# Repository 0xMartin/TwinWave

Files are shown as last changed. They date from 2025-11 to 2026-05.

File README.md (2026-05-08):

<div align="center">

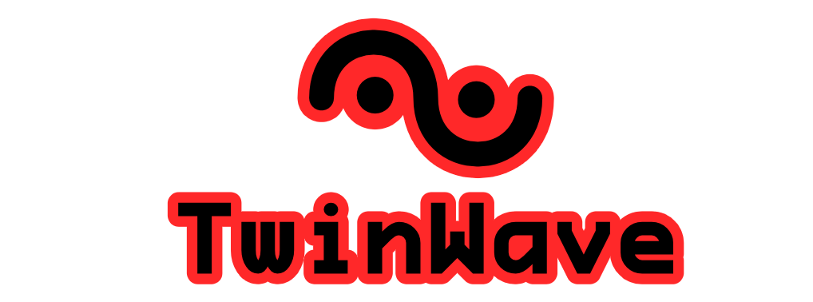
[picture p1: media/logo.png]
TwinWave Logo


#### Wi‑Fi & Sub‑GHz GPIO Module for Flipper Zero

🌐 **[View Project Website](https://0xmartin.github.io/TwinWave/)** 🌐

📋 **[View PCB Project on OSHWLab](https://oshwlab.com/martin.krcma1/flipper-wifi-and-433mhz-shield)** 📋






Compact GPIO module designed for Flipper Zero, combining 2.4 GHz Wi-Fi and 433 MHz Sub-GHz.

</div>

<div align="center">

<table>
<tr>
<td align="center" width="50%">
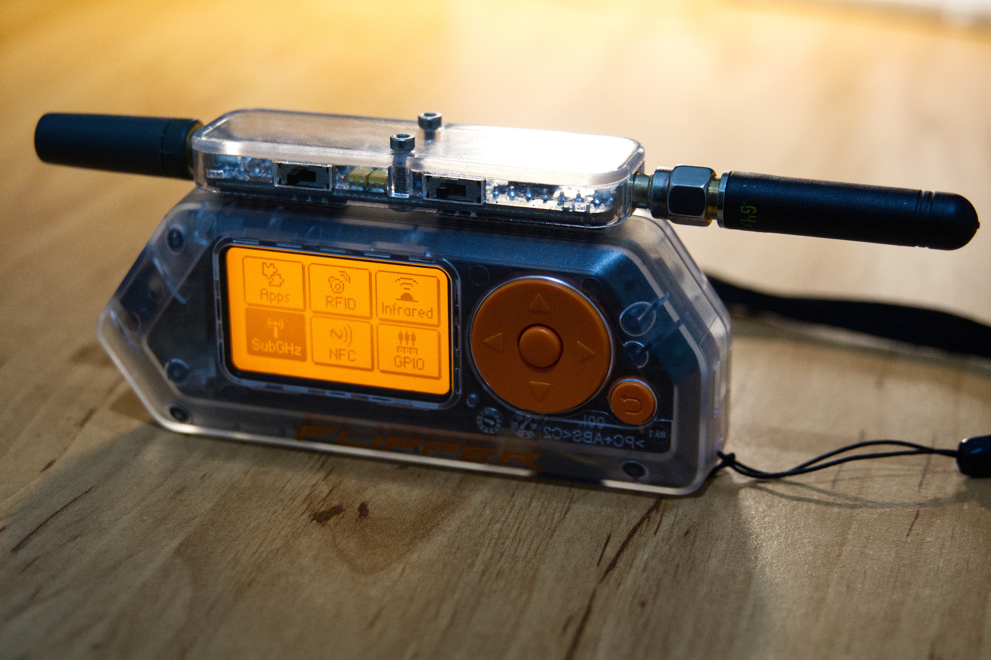
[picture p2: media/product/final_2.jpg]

</td>
<td align="center" width="50%">
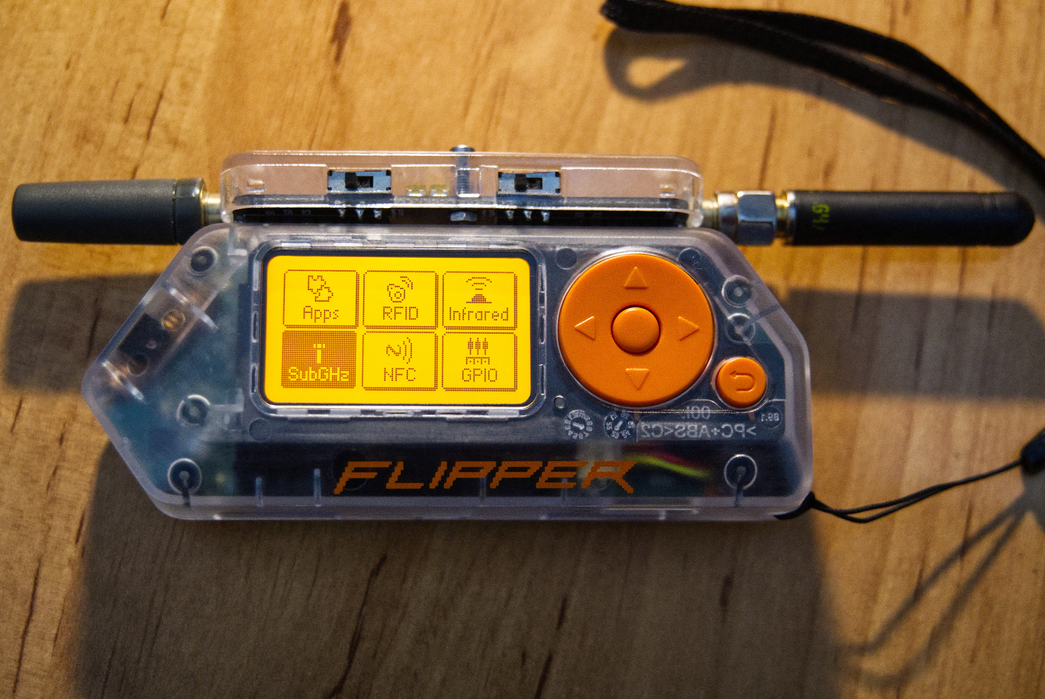
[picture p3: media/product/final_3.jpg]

</td>
</tr>
</table>

<br>

<a href="https://youtu.be/bnLjusv_fXI">
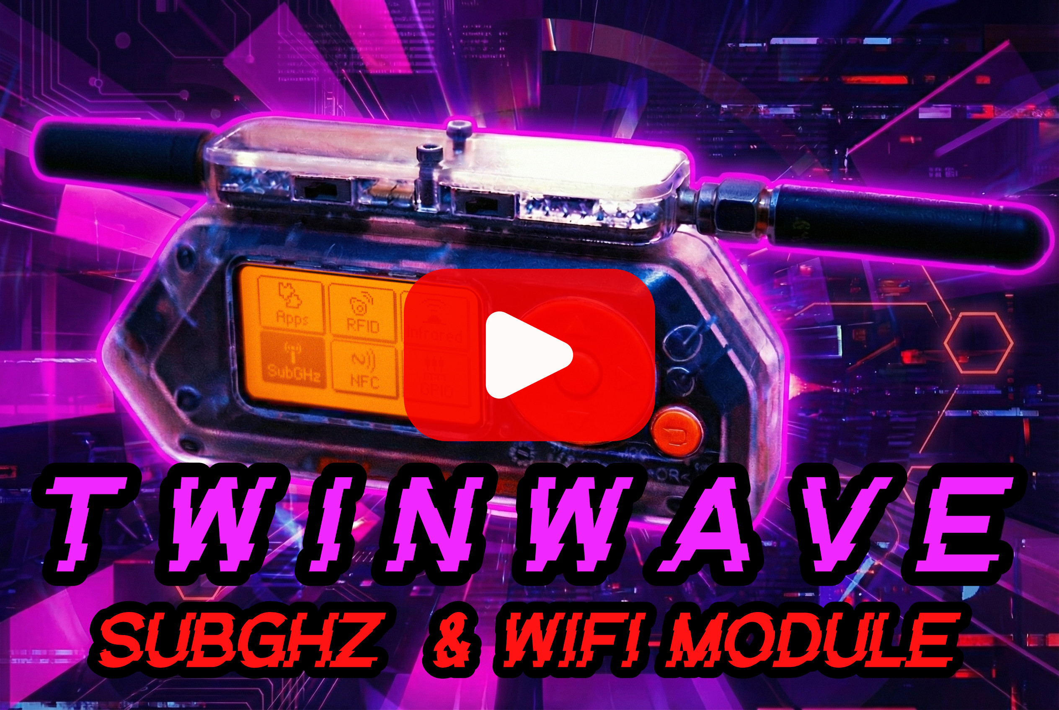
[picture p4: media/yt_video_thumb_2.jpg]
Watch the video
    
</a>

<br>

<sub><em>📺 Click to watch TwinWave in action on YouTube</em></sub>

</div>

<br>

The module is designed to be **as compact as possible**, with replaceable antennas and the ability to remain permanently installed in the port. Two micro switches allow you to activate or deactivate the Wi‑Fi and Sub‑GHz radios, preventing unnecessary power draw when not in use.

<br>

### 📦 Manufacturing Files & Project

- **PCB Manufacturing:** Gerber files, Bill of Materials (BOM), and Pick and Place data for PCB manufacturing are available in the **[./hardware/export](./hardware/export)** directory.
- **EasyEDA Project:** The complete PCB project can be found in the **[./hardware](./hardware)** directory and can be opened in **EasyEDA Pro**.
- **PCB Stackup:** Use **JLC04161H-7628** (4-layer, 1.6mm, 7628 prepreg). This is a standard JLCPCB stackup with the following layer structure:
  | Layer | Material | Thickness |
  |-------|----------|----------|
  | Top Layer | Copper | 0.035mm |
  | Prepreg | 7628×1 | 0.21040mm |
  | Inner Layer L2 | Copper | 0.0152mm |
  | Core | Core | 1.065mm |
  | Inner Layer L3 | Copper | 0.0152mm |
  | Prepreg | 7628×1 | 0.21040mm |
  | Bottom Layer | Copper | 0.035mm |
  
  Total thickness: ~1.1mm H/HOZ with copper
 
> [!NOTE]
> **Pin Header Assembly:** It is recommended to **assemble the pin header yourself** (GPIO connector). This allows you to **adjust the pin length** to perfectly fit your specific Flipper Zero configuration – whether it has a protective case or not.

---

## ✨ Key Features

<table>
<tr>
<td width="50%">

### 🔌 Hardware
- **Dual radios** – Wi‑Fi 2.4 GHz + Sub‑GHz 433 MHz
- **Replaceable antennas** – 2× SMA female connectors
- **Power switches** – Independent Wi‑Fi/Sub‑GHz power control
- **Compact design** – Small form factor for easy use in any situation

</td>
<td width="50%">

### 💻 Software & Chips
- **ESP32-PICO-V3-02** – Wi‑Fi connectivity
- **TI CC1101** – Sub‑GHz transceiver
- **Marauder compatible** – ESP32 Marauder support
- **Easy updates** – UART firmware flashing

</td>
</tr>
</table>

---

## 📋 Technical Specifications

| Category | Details |
|---|---|
| **Radios** | Wi‑Fi 2.4 GHz (ESP32‑PICO‑V3‑02) <br> Sub‑GHz 433 MHz (TI CC1101) |
| **Antennas** | 2× SMA female connectors (Wi‑Fi + 433 MHz) |
| **Power** | Supplied from Flipper GPIO (3.3V, GND) |
| **ESP32 Interface** | UART/Serial via Flipper GPIO <br> Firmware update via external USB‑TTL |
| **CC1101 Interface** | SPI bus (shared with Flipper) |
| **Indicators** | Power LEDs and ESP32 RX and TX LEDs |
| **Compatibility** | Flipper Zero with GPIO header |
| **Dimensions** | Compact form factor, designed for permanent installation |

---

## ⚡ Power Consumption

<details>
<summary><b>📊 Click to view Power Consumption Measurements</b></summary>

<br>

Power consumption measured using oscilloscope in different operating modes:

<div align="center">

<table>
    <tr>
        <td align="center">
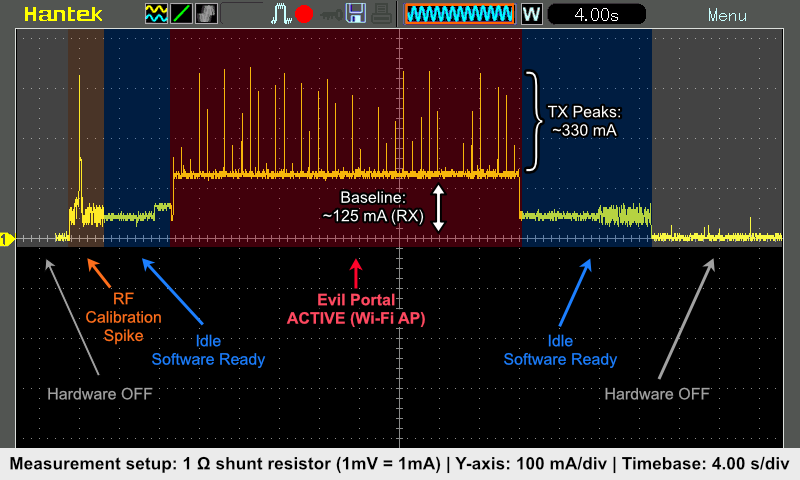
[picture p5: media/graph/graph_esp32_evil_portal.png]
Power consumption - Evil Portal mode
            <br/>
            <sub><strong>Evil Portal Mode</strong> – Power consumption during Evil Portal operation</sub>
        </td>
    </tr>
    <tr>
        <td align="center">
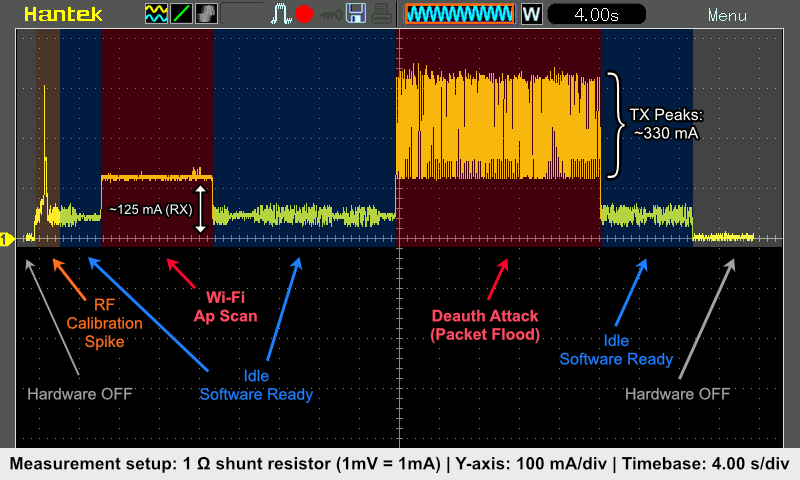
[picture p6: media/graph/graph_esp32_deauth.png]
Power consumption - ESP32 Deauth
            <br/>
            <sub><strong>ESP32 Deauth Detail</strong> – Detailed ESP32 power draw during deauthentication activity</sub>
        </td>
    </tr>
    <tr>
        <td align="center">
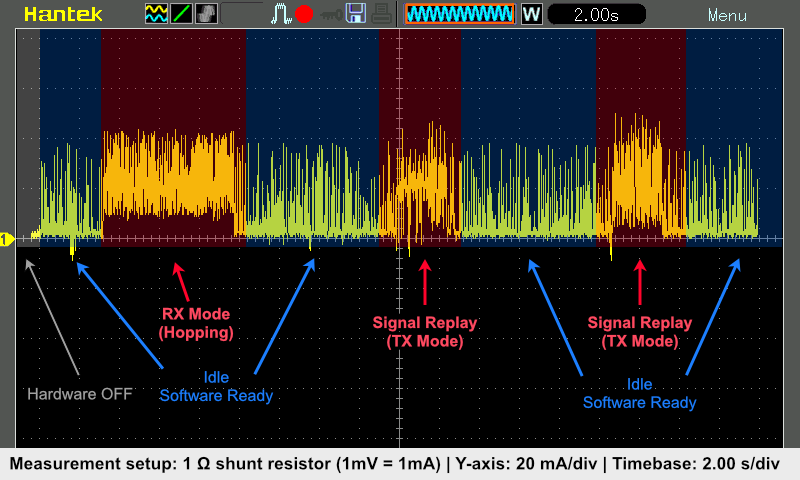
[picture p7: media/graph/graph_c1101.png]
Power consumption - CC1101 Detail
            <br/>
            <sub><strong>CC1101 Detail</strong> – Detailed CC1101 power draw during read/replay activity</sub>
        </td>
    </tr>
</table>

</div>

> [!NOTE]
> These measurements help you understand the power requirements when using the module with Flipper Zero. Use the power switches to disable unused radios and save battery.

</details>

---

## ⚙️ Quick Start Guide

### Step-by-Step

1. **📡 Attach Antennas**
   - Connect 2.4 GHz antenna to the Wi‑Fi SMA connector
   - Connect 433 MHz antenna to the Sub‑GHz SMA connector

2. **🔌 Install Module**
   - Carefully plug the module onto Flipper Zero's GPIO header
   - Ensure proper alignment and secure connection

3. **⚡ Enable Radios**
   - Use micro switches to enable Wi‑Fi and/or Sub‑GHz as needed
   - LEDs will indicate active radios

4. **🚀 Start Experimenting**
   - Use Flipper's serial/terminal to interact with ESP32
   - Integrate CC1101 into your Sub‑GHz workflows

> [!WARNING]
> **Never transmit without antennas connected!** This can damage the RF stages.

---

## 🛠️ ESP32 Marauder Firmware

> [!NOTE]
> The firmware is a **port** of [ESP32 Marauder](https://github.com/justcallmekoko/ESP32Marauder) by **justcallmekoko**, specifically adapted for the `ESP32-PICO-V3-02` chip.

### 📥 Downloads & Flashing

Download precompiled binaries from repository releases: **`MARAUDER-vX.Y.Z-ESP32-PICO-V3-02.zip`**

#### ⚡ Web Flasher (Recommended)

The easiest way to flash firmware — directly from your browser, no installation required!

**[🚀 Open Web Flasher](https://0xmartin.github.io/TwinWave/flash.html)**

- ✓ Automatically downloads the latest firmware version
- ✓ Supports custom firmware upload
- ✓ Works in Chrome, Edge, and Opera browsers
- ✓ Step-by-step wizard guides you through the process

📖 **For manual flashing instructions and build guide, see [`firmware/README.md`](./firmware/README.md)**

---

## 📐 Technical Documentation

<details>
<summary><b>🔍 Click to view Schematic</b></summary>

<br>

<div align="center">
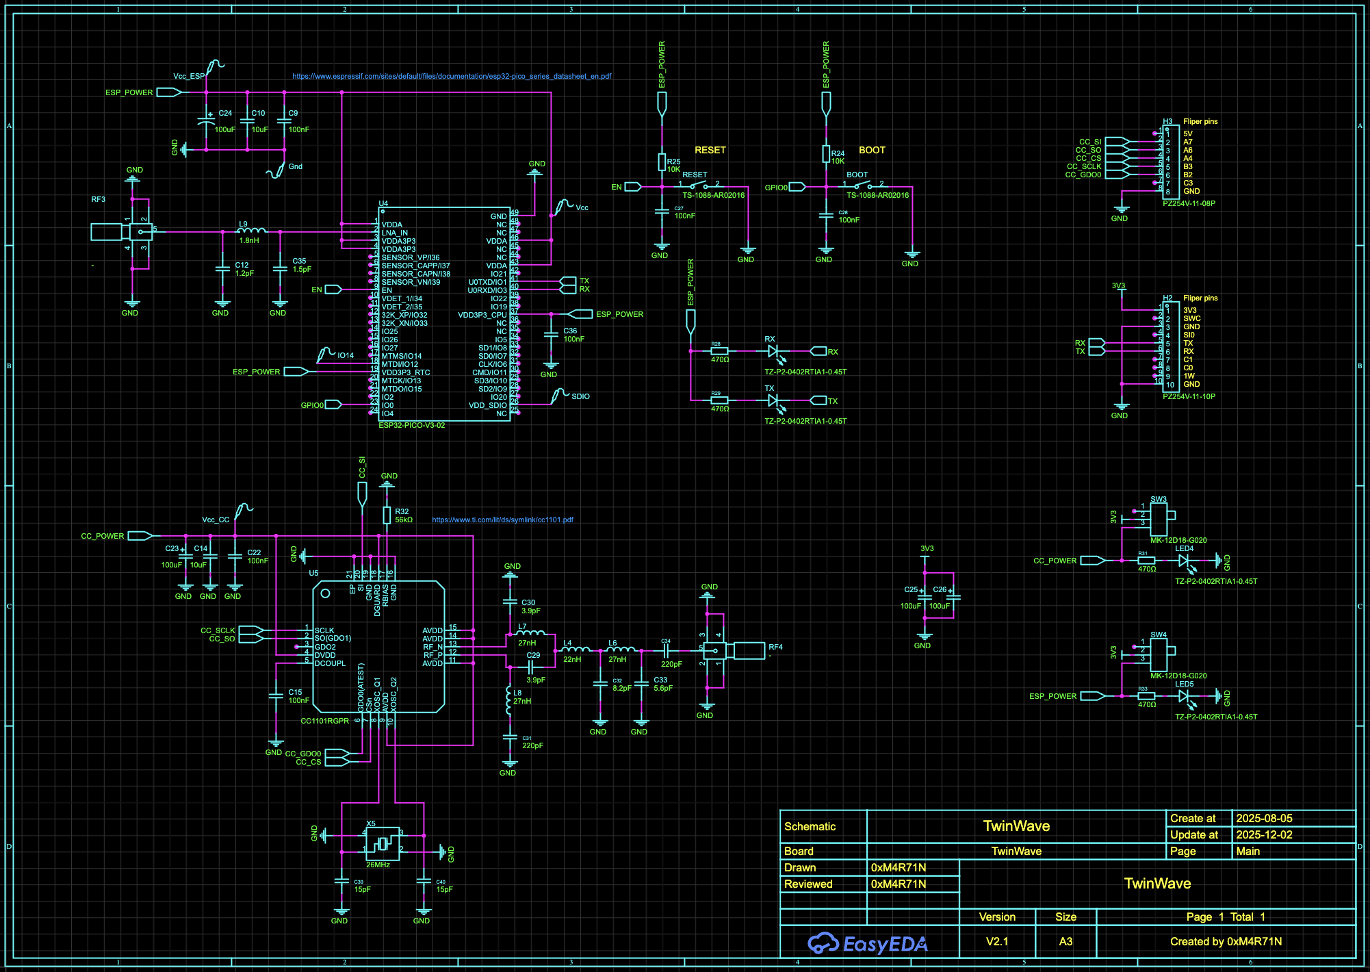
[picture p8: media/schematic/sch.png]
Circuit Schematic
    
    <sub><em>Complete circuit schematic with pinout details</em></sub>
</div>

</details>

<details>
<summary><b>🔍 Click to view PCB Design</b></summary>

<br>

<div align="center">
    <table>
        <tr>
            <td align="center" width="50%">
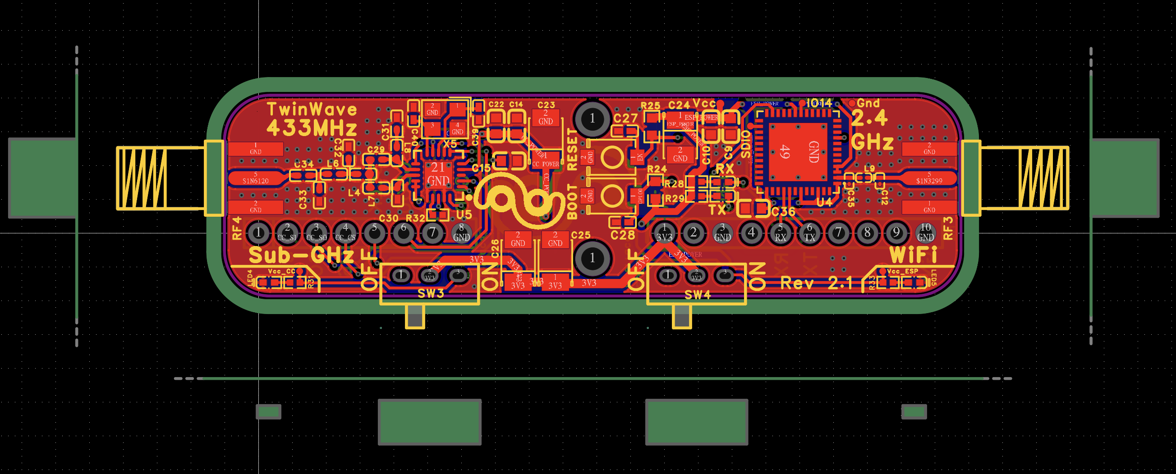
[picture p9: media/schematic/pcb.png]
PCB Top View
                <br/>
                <sub><strong>Top View</strong> – Component placement</sub>
            </td>
            <td align="center" width="50%">
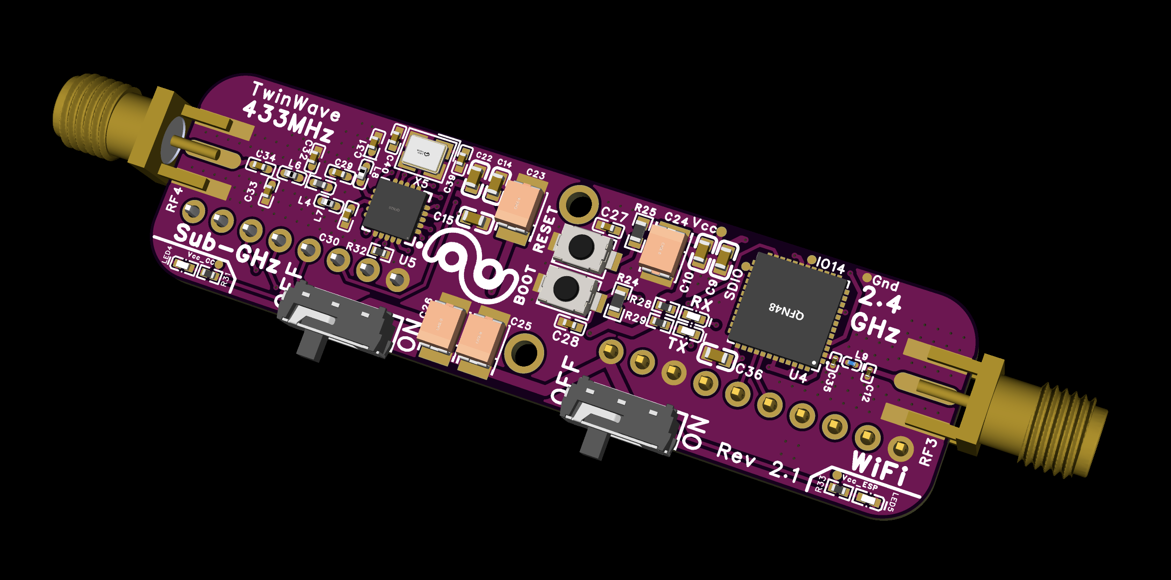
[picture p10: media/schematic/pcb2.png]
PCB 3D View
                <br/>
                <sub><strong>3D View</strong> – Layout visualization</sub>
            </td>
        </tr>
    </table>
</div>

</details>

<details>
<summary><b>📦 Click to view Case Dimensions</b></summary>

<br>

<div align="center">
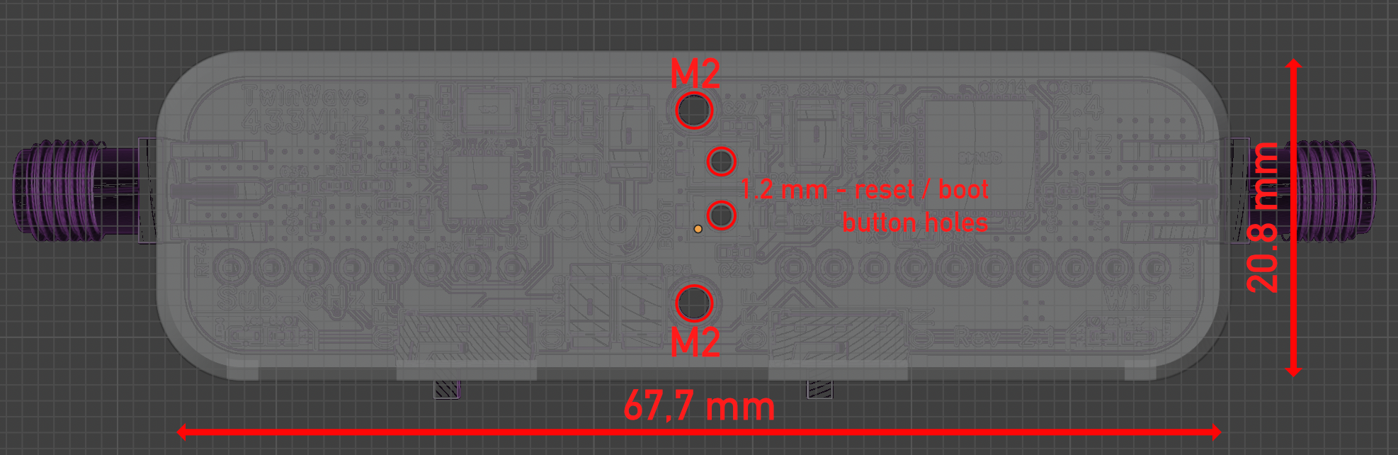
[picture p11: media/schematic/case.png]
Case Dimensions
    
    <sub><em>Case dimensions and form factor</em></sub>
</div>

</details>

---

## ⚠️ RF Safety & Legal

> [!WARNING]
> - **NEVER transmit without antenna connected** – can damage RF stages
> - Use properly tuned antennas for 2.4 GHz and 433 MHz
> - User is **fully responsible** for legal compliance
> - **Lab/experimental use only** – not certified for commercial use
> - Do NOT use in life‑support or safety‑critical systems

---

## 📜 License & Credits

### License

**Hardware:** [CC-BY-NC-SA-4.0 (Creative Commons Attribution-NonCommercial-ShareAlike)](hardware/LICENSE.txt)

**Firmware:** [MIT License (Based on ESP32 Marauder)](firmware/LICENSE.txt)

For details, see the LICENSE file in each subfolder.

**NOTICE:** The firmware is a derivative work of ESP32 Marauder by justcallmekoko, used under the MIT License. See [firmware/NOTICE](firmware/NOTICE).

### 👨‍💻 Authors
<table>
<tr>
<td>

**🔧 Hardware Design**  
[0xM4R71N](https://github.com/0xMartin) – PCB design, 3D case, Marauder port for ESP32-PICO-V3-02

</td>
</tr>
<tr>
<td>

**💻 Original Firmware**  
[justcallmekoko](https://github.com/justcallmekoko) – ESP32 Marauder firmware author

</td>
</tr>
</table>

---

<div align="center">

### 🌟 If you find this project useful, please consider giving it a star!



__Made with ❤️ for the Flipper Zero communit__

</div>

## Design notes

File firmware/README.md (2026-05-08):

# ESP32 Marauder Firmware

> ⚡ **Based on [ESP32 Marauder](https://github.com/justcallmekoko/ESP32Marauder) by [justcallmekoko](https://github.com/justcallmekoko)**
>
> This is a custom port adapted for the **TwinWave** module with `ESP32-PICO-V3-02` chip.
> All credit for the original firmware goes to the Marauder project and its contributors.

📖 For complete project documentation, see the [main README](../README.md)

---

## 📋 Overview

| Property | Value |
|---|---|
| **Base Firmware** | ESP32 Marauder v1.12.1 |
| **Target Chip** | ESP32-PICO-V3-02 |
| **Flash Size** | 8MB |
| **Framework** | Arduino (PlatformIO) |
| **Board Config** | `GENERIC_ESP32` |

---

## ⚡ Quick Start

### Option 1: Flash Precompiled Binaries

Download the latest release: **`MARAUDER-vX.Y.Z-ESP32-PICO-V3-02.zip`**

The package contains:
- `bootloader.bin` – ESP32 bootloader
- `firmware.bin` – Main firmware image
- `partitions.bin` – Partition table

**Flash using esptool:**

```bash
# Install esptool
pip install esptool

# Flash firmware (adjust port as needed)
esptool --chip esp32 --port /dev/cu.usbserial-0001 --baud 115200 write-flash -z \
    0x1000 bootloader.bin \
    0x8000 partitions.bin \
    0x10000 firmware.bin
```

> **Port examples:** `/dev/cu.usbserial-*` (macOS), `/dev/ttyUSB0` (Linux), `COM3` (Windows)

### Option 2: Build from Source

1. **Install PlatformIO** – [VS Code extension](https://platformio.org/install/ide?install=vscode) or CLI
2. **Open this folder** in VS Code with PlatformIO
3. **Connect USB-TTL adapter** to the TwinWave GPIO pins (see pinout below)
4. **Enter flash mode** – Hold BOOT, press RESET, release both
5. **Click Upload** (→) in PlatformIO toolbar

---

## 🔌 UART Connection (Flashing)

Connect a USB-TTL adapter (CP2102, CH340, FT232) to the **10-pin header** on the bottom of TwinWave PCB:

| TwinWave Pin | USB-TTL Adapter |
|---|---|
| Pin 1 (3V3) | VCC ⚠️ **3.3V only!** |
| Pin 3 (GND) | GND |
| Pin 5 (RX) | TX |
| Pin 6 (TX) | RX |

> ⚠️ **Warning:** Using 5V will permanently damage the ESP32!

### Enter Flash Mode

1. Hold **BOOT** button
2. Press **RESET** button
3. Release both buttons
4. The module is now in flash mode

---

### PlatformIO Settings

Key settings from [platformio.ini](platformio.ini):

```ini
platform = espressif32@5.2.0
board = esp32dev
framework = arduino
board_build.flash_mode = dio
board_build.partitions = default_8MB.csv
board_upload.flash_size = 8MB
```

### Dependencies

| Library | Version | Purpose |
|---|---|---|
| NimBLE-Arduino | ^1.4.1 | Bluetooth Low Energy |
| LinkedList | 0.0.0-alpha | Data structures |
| ESP32Ping | ^1.7 | Network diagnostics |
| AsyncTCP | latest | Async TCP connections |
| ESPAsyncWebServer | latest | Web server for Evil Portal |
| ArduinoJson | ^6.19.4 | JSON parsing |
| Adafruit MAX1704X | ^1.0.3 | Battery monitoring |
| MicroNMEA | ^2.0.6 | GPS parsing |
| EspSoftwareSerial | ^8.2.0 | Software serial communication |

---

## ⚠️ Troubleshooting

### Upload fails / "Failed to connect"

- Ensure you're in **flash mode** (BOOT + RESET sequence)
- Check USB-TTL connections (TX↔RX crossed)
- Try lower baud rate: `upload_speed = 57600`
- Verify correct serial port in `platformio.ini`

### "No serial data available"

- Check baud rate is **115200**
- Verify TX/RX connections
- Try different USB-TTL adapter

### Build errors

- Run `pio pkg update` to update libraries
- Clean build: `pio run -t clean`
- Check PlatformIO version compatibility

---

## 📜 Credits & License

- **Original Firmware:** [justcallmekoko](https://github.com/justcallmekoko) – ESP32 Marauder
- **Port/Adaptation:** [0xM4R71N](https://github.com/0xMartin) – ESP32-PICO-V3-02 adaptation

> ⚖️ This firmware is subject to the original [ESP32 Marauder license](https://github.com/justcallmekoko/ESP32Marauder). See the original repository for license terms.

---

## 🔗 Links

- 🏠 [TwinWave Project](https://github.com/0xMartin/TwinWave)
- 🌐 [Project Website](https://0xmartin.github.io/TwinWave/)
- 📖 [ESP32 Marauder Wiki](https://github.com/justcallmekoko/ESP32Marauder/wiki)
- 🛠️ [PlatformIO Documentation](https://docs.platformio.org/)

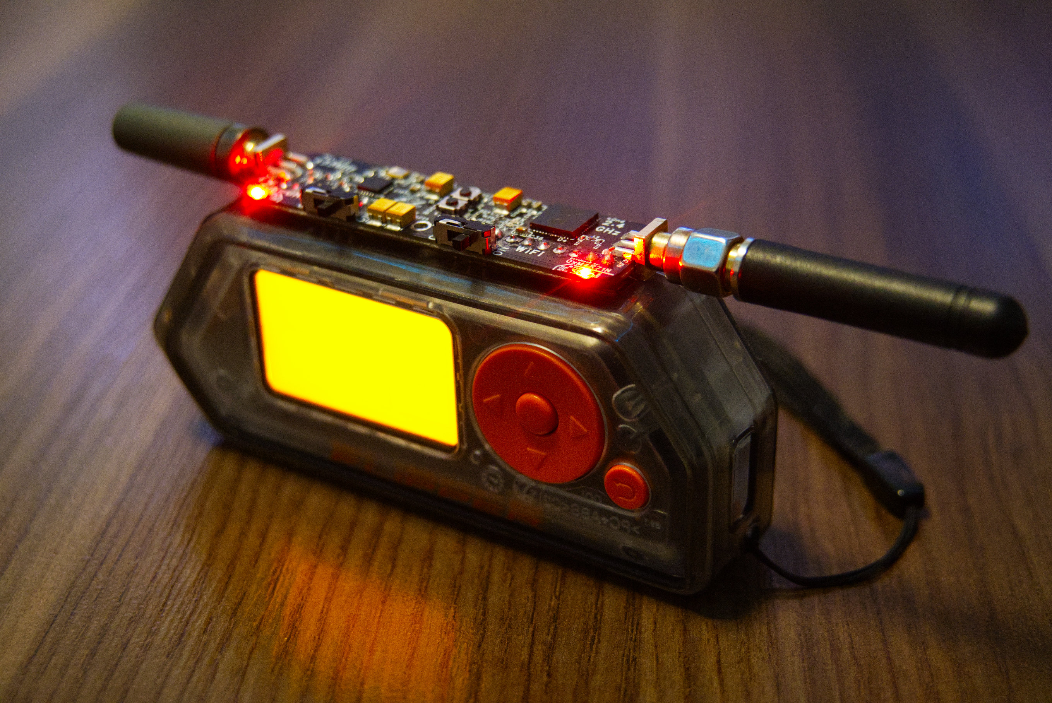
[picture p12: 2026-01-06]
media/product/final_6.jpg

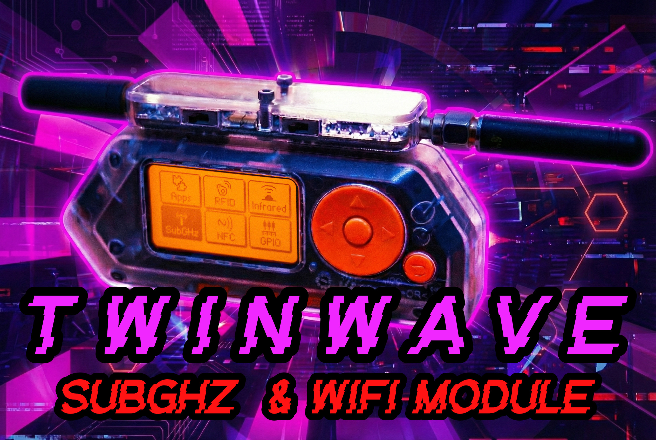
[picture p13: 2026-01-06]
media/yt_video_thumb_1.jpg

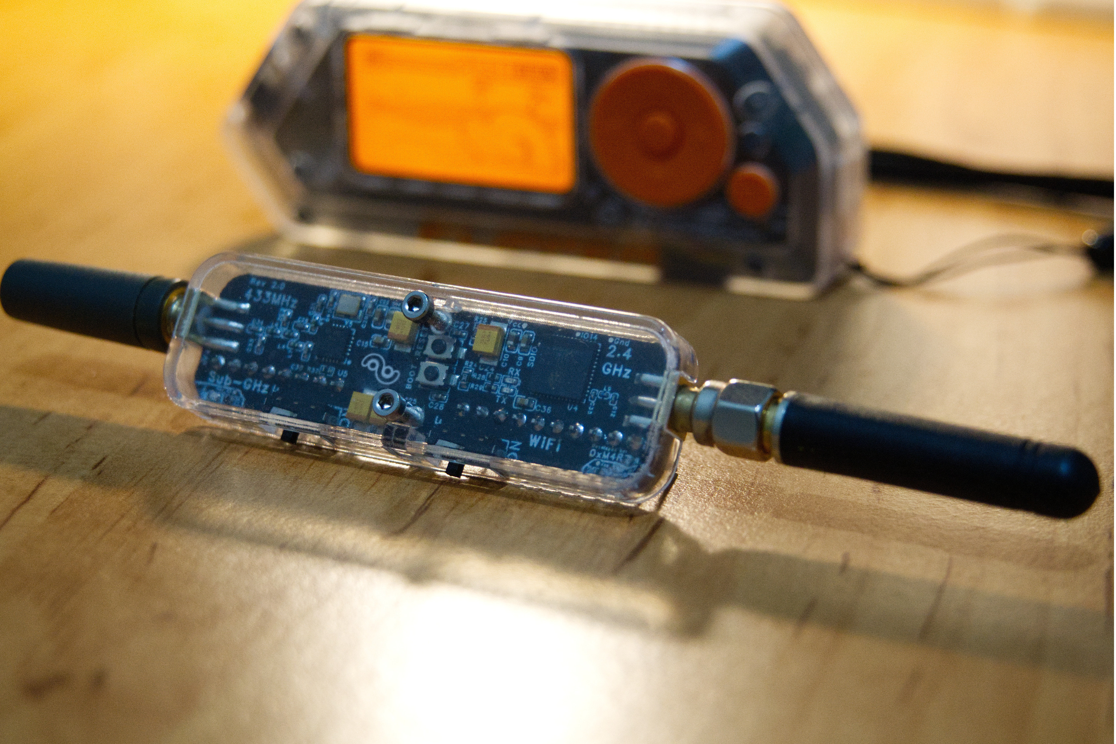
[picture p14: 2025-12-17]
docs/media/product/final_1.jpg

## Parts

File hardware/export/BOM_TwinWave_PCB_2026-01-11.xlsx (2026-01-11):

No. | Quantity | Comment | Designator | Footprint | Value | Manufacturer Part | Manufacturer | Supplier Part | Supplier
1 | 2 | TS-1088-AR02016 | BOOT,RESET | SW-SMD_L3.9-W3.0-P4.45 |  | TS-1088-AR02016 | XUNPU(讯普) | C720477 | LCSC
2 | 4 | 100nF | C9,C15,C22,C36 | C0603 | 100nF | CC0603KRX7R9BB104 | YAGEO(国巨) | C14663 | LCSC
3 | 2 | 10uF | C10,C14 | C0603 | 10uF | CL10A106MP8NNNC | SAMSUNG(三星) | C85713 | LCSC
4 | 1 | 1.2pF | C12 | C0201 | 1.2pF | GRM0335C1H1R2BA01D | muRata(村田) | C85895 | LCSC
5 | 3 | 100uF | C23,C25,C26 | CASE-B_3528 | 100uF | TAJB107K006RNJ | Kyocera AVX | C16133 | LCSC
6 | 1 | 100uF | C24 | CASE-B_3528-1 | 100uF | TPSB107K006R0250 | Kyocera AVX | C597710 | LCSC
7 | 2 | 100nF | C27,C28 | C0402 | 100nF | CC0402KRX7R7BB104 | YAGEO(国巨) | C60474 | LCSC
8 | 2 | 3.9pF | C29,C30 | C0402 | 3.9pF | 0402CG3R9C500NT | FH(风华) | C1566 | LCSC
9 | 2 | 220pF | C31,C34 | C0402 | 220pF | CC0402JRNPO9BN221 | YAGEO(国巨) | C107001 | LCSC
10 | 1 | 8.2pF | C32 | C0402 | 8.2pF | CC0402BRNPO9BN8R2 | YAGEO(国巨) | C327205 | LCSC
11 | 1 | 5.6pF | C33 | C0402 | 5.6pF | CC0402BRNPO9BN5R6 | YAGEO(国巨) | C505468 | LCSC
12 | 1 | 1.5pF | C35 | C0201 | 1.5pF | GRM0335C1H1R5BA01D | muRata(村田) | C161414 | LCSC
13 | 2 | 15pF | C39,C40 | C0402 | 15pF | CC0402JRNPO9BN150 | YAGEO(国巨) | C106997 | LCSC
14 | 6 | Test-Point | Gnd,IO14,SDIO,Vcc,Vcc_CC,Vcc_ESP | Test-Point-0.5mm
15 | 1 | PZ254V-11-10P | H2 | HDR-TH_10P-P2.54-V-M |  | PZ254V-11-10P | XFCN(兴飞) | C492409 | LCSC
16 | 1 | PZ254V-11-08P | H3 | HDR-TH_8P-P2.54-V-M |  | PZ254V-11-08P | XFCN(兴飞) | C492407 | LCSC
17 | 1 | 22nH | L4 | L0402 | 22nH | LQG15HS22NJ02D | muRata(村田) | C12670 | LCSC
18 | 3 | 27nH | L6,L7,L8 | L0402-RD | 27nH | LQG15HS27NJ02D | muRata(村田) | C12669 | LCSC
19 | 1 | 1.8nH | L9 | L0201-RD | 1.8nH | LQP03TN1N8B02D | muRata(村田) | C98040 | LCSC
20 | 4 | TZ-P2-0402RTIA1-0.45T | LED4,LED5,RX,TX | LED0402-RD_RED |  | TZ-P2-0402RTIA1-0.45T | TUOZHAN(拓展光电) | C779449 | LCSC
21 | 2 | 10K | R24,R25 | R0603 |  | RC0603DR-0710KL | YAGEO(国巨) | C137819 | LCSC
22 | 4 | 470Ω | R28,R29,R31,R33 | R0402 | 470Ω | 0402WGF4700TCE | UNI-ROYAL(厚声) | C25117 | LCSC
23 | 1 | 56kΩ | R32 | R0402 | 56kΩ | 0402WGF5602TCE | UNI-ROYAL(厚声) | C25796 | LCSC
24 | 2 | - | RF3,RF4 | SMA-SMD_BWSMA-KE-P001 | - | BWSMA-KE-P001 | BAT WIRELESS(蝙蝠无线) | C496550 | LCSC
25 | 2 | MK-12D18-G020 | SW3,SW4 | SW-TH_MK-12D18-G040 |  | MK-12D18-G020 | G-Switch(品赞) | C3019727 | LCSC
26 | 1 | ESP32-PICO-V3-02 | U4 | QFN-48_L7.0-W7.0-P0.50-BL-EP5.1 |  | ESP32-PICO-V3-02 | ESPRESSIF(乐鑫) | C908392 | LCSC
27 | 1 | CC1101RGPR | U5 | QFN-20_L4.0-W4.0-P0.5-TL-EP |  | CC1101RGPR | TI(德州仪器) | C29953 | LCSC
28 | 1 | 26MHz | X5 | CRYSTAL-SMD_4P-L3.2-W2.5-BL | 26MHz | X322526MMB4SI | YXC(扬兴晶振) | C15192 | LCSC

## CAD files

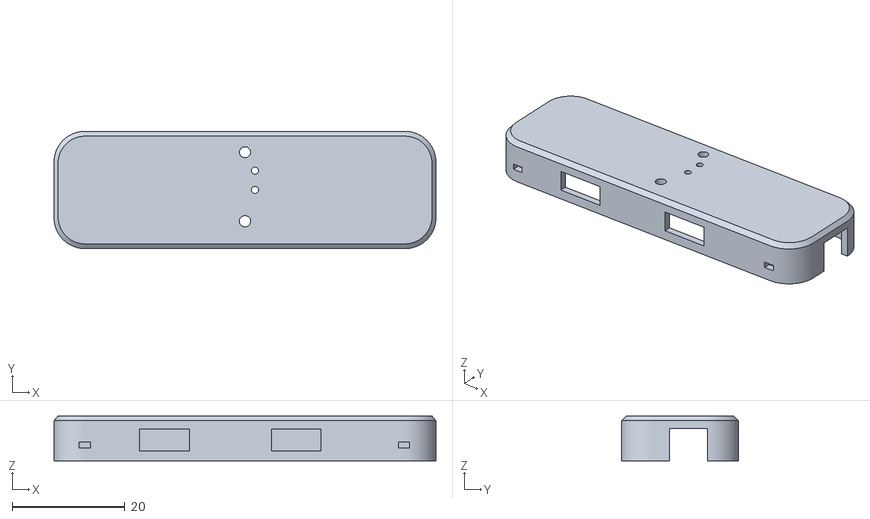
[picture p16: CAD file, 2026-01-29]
hardware/case/TwinWave_3D_Shell.stl
67.7 x 20.8 x 7.97

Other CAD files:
hardware/case/case.blend

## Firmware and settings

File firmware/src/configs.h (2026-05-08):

#pragma once

#ifndef configs_h

  #define configs_h

  #define POLISH_POTATO

  //#define DEVELOPER

  //// BOARD TARGETS
  //#define MARAUDER_M5STICKC
  //#define MARAUDER_M5STICKCP2
  //#define MARAUDER_MINI
  //#define MARAUDER_V4
  //#define MARAUDER_V6
  //#define MARAUDER_V6_1
  //#define MARAUDER_V7
  //#define MARAUDER_V7_1
  //#define MARAUDER_KIT
  #define GENERIC_ESP32
  //#define MARAUDER_FLIPPER
  //#define MARAUDER_MULTIBOARD_S3
  //#define ESP32_LDDB
  //#define MARAUDER_DEV_BOARD_PRO
  //#define XIAO_ESP32_S3
  //#define MARAUDER_REV_FEATHER
  //#define MARAUDER_CYD_MICRO // 2432S028
  //#define MARAUDER_CYD_2USB // Another 2432S028 but it has tWo UsBs OoOoOoO
  //#define MARAUDER_CYD_GUITION // ESP32-2432S024 GUITION
  //#define MARAUDER_CYD_3_5_INCH
  //#define MARAUDER_C5
  //#define MARAUDER_CARDPUTER
  //#define MARAUDER_CARDPUTER_ADV
  //#define MARAUDER_V8
  //#define MARAUDER_MINI_V3
  //#define DUAL_MINI_C5
  //// END BOARD TARGETS

  #define JSON_SETTING_SIZE 2048

  #define MARAUDER_VERSION "v1.12.1"

  #define GRAPH_REFRESH   100

  #define TRACK_EVICT_SEC 90 // Seconds before marking tracked MAC as tombstone

  #define DUAL_BAND_CHANNELS 51

  #define DISPLAY_BUFFER_LIMIT 20

  #define MODE_OFF 0
  #define MODE_RAINBOW 1
  #define MODE_ATTACK 2
  #define MODE_SNIFF 3
  #define MODE_CUSTOM 4

  //// HARDWARE NAMES
  #ifdef MARAUDER_M5STICKC
    #define HARDWARE_NAME "M5Stick-C Plus"
  #elif defined(MARAUDER_M5STICKCP2)
    #define HARDWARE_NAME "M5Stick-C Plus2"
  #elif defined(MARAUDER_CARDPUTER)
    #define HARDWARE_NAME "M5 Cardputer"
  #elif defined(MARAUDER_CARDPUTER_ADV)
    #define HARDWARE_NAME "M5 Cardputer ADV"
  #elif defined(MARAUDER_MINI)
    #define HARDWARE_NAME "Marauder Mini"
  #elif defined(MARAUDER_V7)
    #define HARDWARE_NAME "Marauder v7"
  #elif defined(MARAUDER_V7_1)
    #define HARDWARE_NAME "Marauder v7.1"
  #elif defined(MARAUDER_REV_FEATHER)
    #define HARDWARE_NAME "Adafruit Feather ESP32-S2 Reverse TFT"
  #elif defined(MARAUDER_V4)
    #define HARDWARE_NAME "Marauder v4"
  #elif defined(MARAUDER_V6)
    #define HARDWARE_NAME "Marauder v6"
  #elif defined(MARAUDER_V6_1)
    #define HARDWARE_NAME "Marauder v6.1"
  #elif defined(MARAUDER_CYD_MICRO)
    #define HARDWARE_NAME "CYD 2432S028"
  #elif defined(MARAUDER_CYD_2USB)
    #define HARDWARE_NAME "CYD 2432S028 2USB"
  #elif defined(MARAUDER_CYD_3_5_INCH)
    #define HARDWARE_NAME "CYD 3.5inch"
  #elif defined(MARAUDER_CYD_GUITION)
    #define HARDWARE_NAME "CYD 2432S024 GUITION"
  #elif defined(MARAUDER_KIT)
    #define HARDWARE_NAME "Marauder Kit"
  #elif defined(MARAUDER_FLIPPER)
    #define HARDWARE_NAME "Flipper Zero Dev Board"
  #elif defined(MARAUDER_MULTIBOARD_S3)
    #define HARDWARE_NAME "Flipper Zero Multi Board S3"
  #elif defined(ESP32_LDDB)
    #define HARDWARE_NAME "ESP32 LDDB"
  #elif defined(MARAUDER_DEV_BOARD_PRO)
    #define HARDWARE_NAME "Flipper Zero Dev Board Pro"
  #elif defined(XIAO_ESP32_S3)
    #define HARDWARE_NAME "XIAO ESP32 S3"
  #elif defined(MARAUDER_C5)
    #define HARDWARE_NAME "ESP32-C5 DevKit"
  #elif defined(MARAUDER_V8)
    #define HARDWARE_NAME "Marauder v8"
  #elif defined(MARAUDER_MINI_V3)
    #define HARDWARE_NAME "Marauder Mini v3"
  #elif defined(DUAL_MINI_C5)
    #define HARDWARE_NAME "Dual Mini C5"
  #else
    #define HARDWARE_NAME "ESP32"
  #endif

  //// END HARDWARE NAMES

 //// BOARD FEATURES
  #if defined(DUAL_MINI_C5)
    #define MARAUDER_MINI_V3
  #endif

  #if defined(MARAUDER_M5STICKC) || defined(MARAUDER_M5STICKCP2)
    //#define FLIPPER_ZERO_HAT
    #define HAS_MINI_KB
    #define HAS_BATTERY
    #define HAS_BT
    #define HAS_BUTTONS
    //#define HAS_NEOPIXEL_LED
    #define HAS_PWR_MGMT
    #define HAS_SCREEN
    #define HAS_MINI_SCREEN
    #define HAS_SD
    #define USE_SD
    #define HAS_TEMP_SENSOR
    #define HAS_GPS
  #endif

  #if defined(MARAUDER_CARDPUTER) || defined(MARAUDER_CARDPUTER_ADV)
    //#define FLIPPER_ZERO_HAT
    #define HAS_MINI_KB
    #define HAS_BT
    #define HAS_BUTTONS
    //#define HAS_NEOPIXEL_LED
    //#define HAS_PWR_MGMT
    //#define HAS_BATTERY
    #define HAS_SCREEN
    #define HAS_MINI_SCREEN
    #define HAS_SD
    #define USE_SD
    #define HAS_TEMP_SENSOR
    #define HAS_GPS

    #ifdef MARAUDER_CARDPUTER_ADV
      #define HAS_BATTERY
      #define BATTERY_ADC_PIN 10
      #define HAS_NEOPIXEL_LED
    #endif
  #endif

  #ifdef MARAUDER_MINI
    //#define FLIPPER_ZERO_HAT
    //#define HAS_BATTERY
    #define HAS_MINI_KB
    #define HAS_BT
    #define HAS_BUTTONS
    #define HAS_NEOPIXEL_LED
    //#define HAS_PWR_MGMT
    #define HAS_SCREEN
    #define HAS_MINI_SCREEN
    #define HAS_SD
    #define USE_SD
    #define HAS_TEMP_SENSOR
    #define HAS_GPS
    #define HAS_NIMBLE_2
    #define HAS_IDF_3
    //#define HAS_C5_SD
    #define HAS_SIMPLEX_DISPLAY
  #endif
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

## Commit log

2025-11-28 Fix formatting in README for ESP32 Marauder firmware
2025-11-29 pcb silkscreen update
    [BOM_TweenWave_PCB2_2025-10-01.xlsx, BOM_TweenWave_PCB2_2025-11-29.xlsx, PickAndPlace_PCB2_2025-10-01.xlsx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]
2025-11-29 Power consuption graphs
2025-12-02 rev 2.1
    [BOM_TweenWave_PCB2_2025-11-29.xlsx, BOM_TweenWave_PCB2_2025-12-02.xlsx, PickAndPlace_PCB2_2025-11-29.xlsx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]
2025-12-02 pcb image update
2025-12-02 schematic 2.1 update
2025-12-17 pcb photo update
2025-12-17 pcb photo
2026-01-04 page update, readme update, pcb update
    [BOM_TweenWave_PCB2_2025-12-02.xlsx, BOM_TweenWave_PCB2_2026-01-04.xlsx, PickAndPlace_PCB2_2025-12-02.xlsx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]
2026-01-06 licence and strucutre update
    [BOM_TwinWave_PCB_2026-01-06.xlsx, PickAndPlace_PCB_2026-01-06.xlsx, TwinWave_3D_Shell.stl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]
2026-01-11 added pcb stackup info
    [BOM_TwinWave_PCB_2026-01-06.xlsx, BOM_TwinWave_PCB_2026-01-11.xlsx, PickAndPlace_PCB_2026-01-06.xlsx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]
2026-01-24 update download links for PCB files to latest versions
2026-01-24 Add brightness filter to hero section
2026-01-27 update PCB background image and adjust size in CSS
2026-01-27 Adjust PCB background image opacity and size for improved visibility
2026-01-28 Add PCB traces glow scan effect with animation to hex overlay
2026-01-29 Case update
    [TwinWave_3D_Shell.stl, case.blend]
2026-01-29 Update .gitignore, fix PCB project file path, and add new media assets
2026-01-30 Refactor code structure for improved readability and maintainability
    [case.blend]
2026-02-28 Add ESP32 Marauder firmware source code and update script
    - Introduced the main firmware source file `esp32_marauder.cpp` containing setup and loop functions, along with various configurations and object initializations for the ESP32 Marauder.
    - Implemented a bash script `update_marauder.sh` to automate the process of updating the firmware, including cloning the repository, copying necessary files, configuring settings, building with Platf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
2026-04-22 Add PCB traces glow scan effect to hex-overlay with animation
2026-11-05 Refactor: Remove settings management and LED control classes
    - Deleted `settings.cpp` and `settings.h` files, removing the settings management functionality.
    - Removed `stickcLED` and `xiaoLED` classes along with their respective header files, eliminating LED control logic.
    - Cleaned up related code that depended on the removed settings and LED classes.
2026-11-05 Add settings management and LED control for various devices
    - Introduced a new Settings class for managing application settings, including WiFi credentials and geofences.
    - Implemented LED control for M5Stick C and Xiao boards, allowing LED behavior to be toggled based on settings.
    - Created utility functions for handling memory usage and converting between MAC addresses and strings.
    - Added support for the Waveshare ESP32-C5-Touch-LCD-3.5 I/O expander, including initialization and control functions.
    - Enhanced the overall structure and organization of the firmware codebase for better maintainability.
